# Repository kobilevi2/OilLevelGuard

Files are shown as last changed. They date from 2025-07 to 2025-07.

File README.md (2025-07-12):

# 🛢️ Oil Level Guard

## 🛢️ Overview

I have an oil tank that supplies heating to my house. After running out of oil more than once in the middle of winter — simply because I forgot to check the tank level — I decided to automate the process.

I developed a simple but effective project that automatically detects when the oil level in the tank drops below a certain threshold. To do this, I installed a liquid presence detector on the tank’s indicator pipe.

The sensor is connected to an ESP32-C6 microcontroller, which transmits the data via Zigbee to my Home Assistant setup.

## 📸 Project Images

Below are images of the final setup and installation:

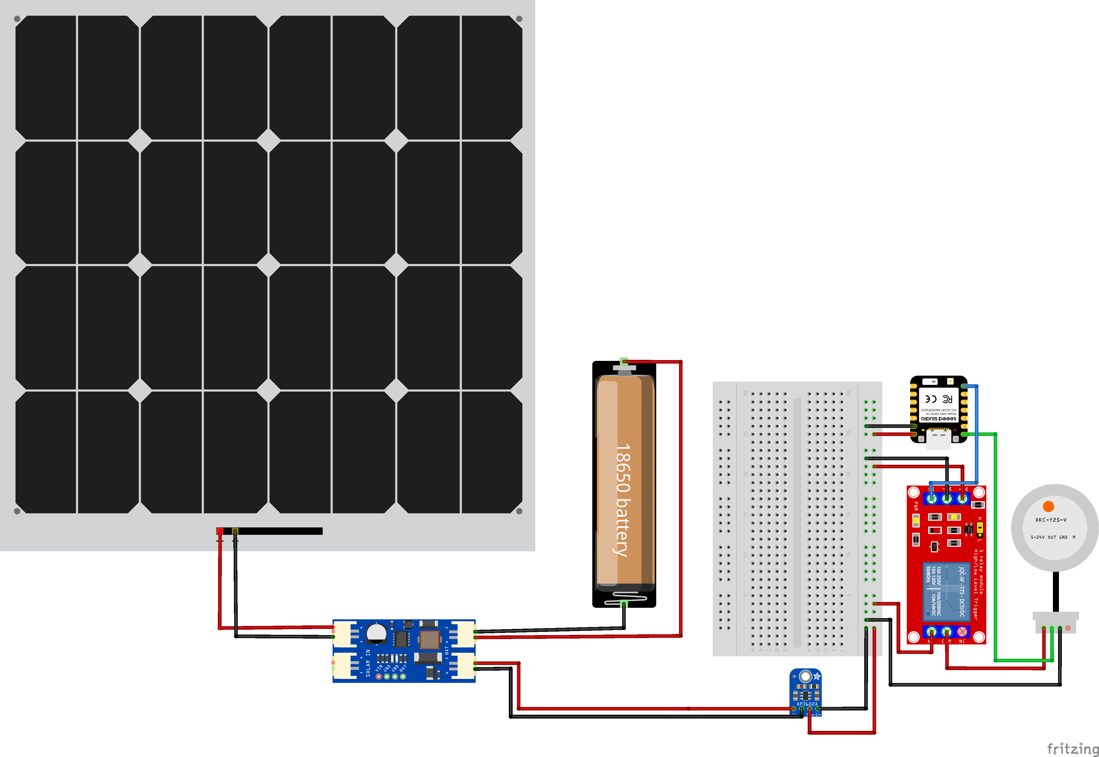
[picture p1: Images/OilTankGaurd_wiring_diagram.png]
Wiring Diagram
- 
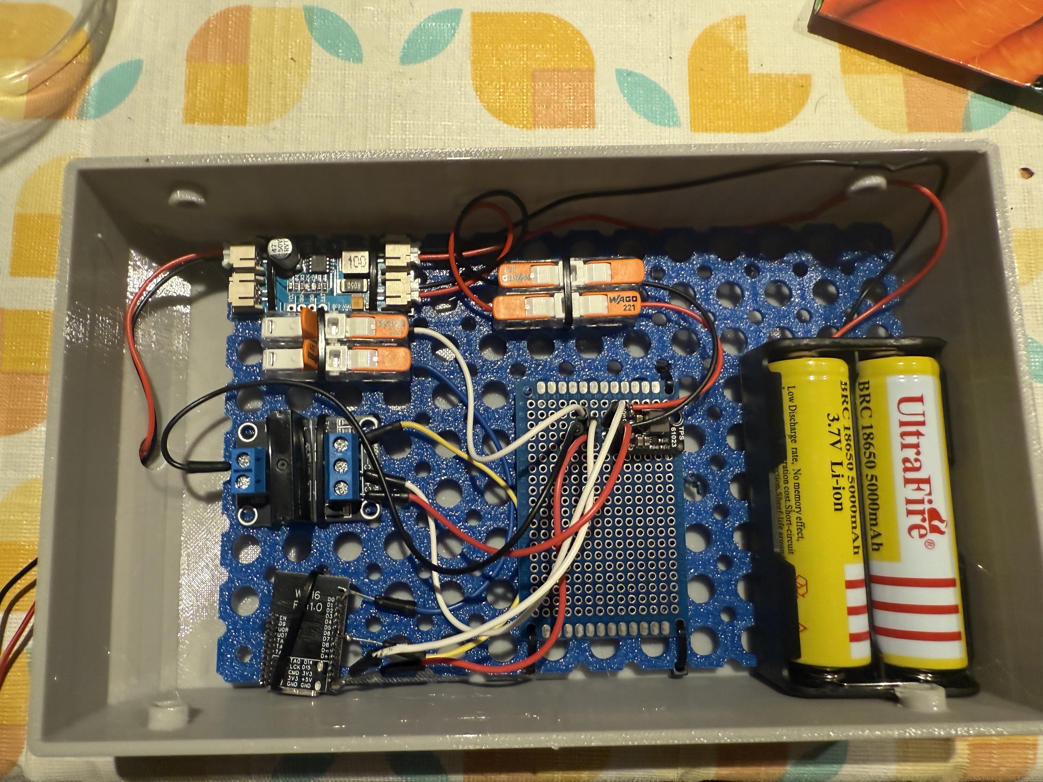
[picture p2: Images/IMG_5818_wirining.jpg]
Inside Wiring Layout
- 
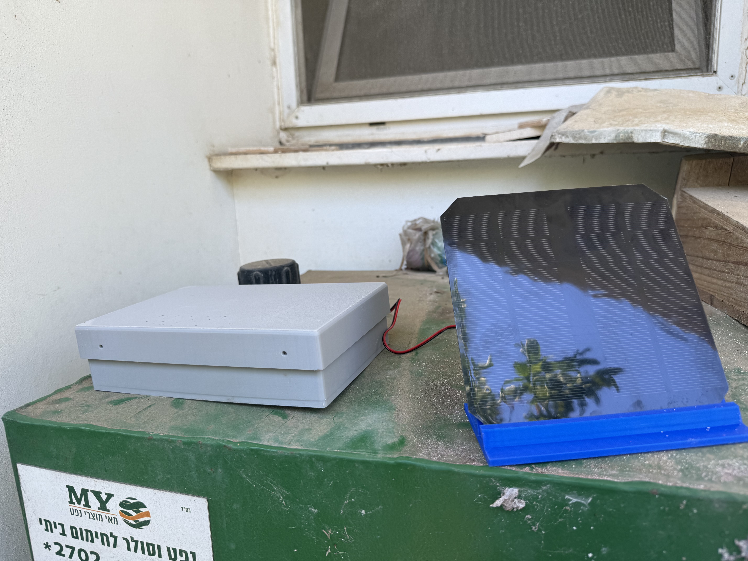
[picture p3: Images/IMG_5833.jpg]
Project Enclosure
- 
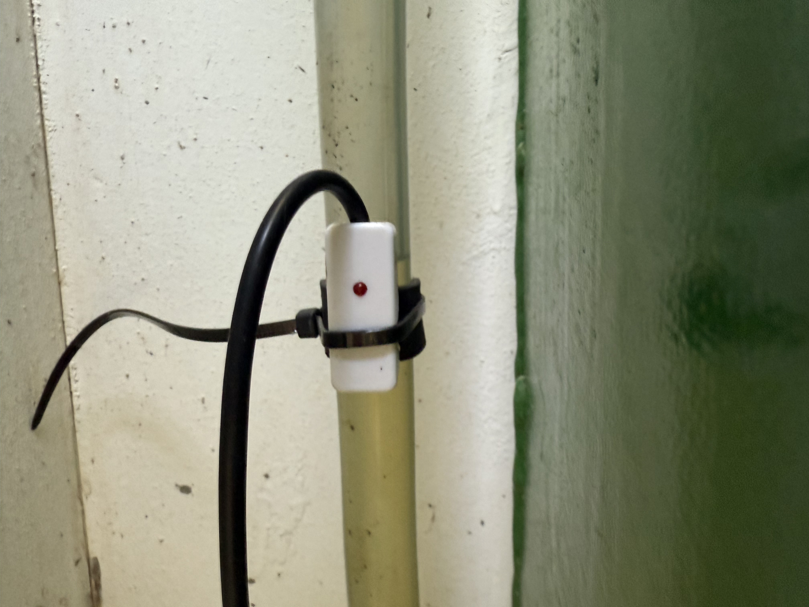
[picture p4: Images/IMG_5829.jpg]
Sensor Mounted on Oil Tank
- 

## 🔋 Power & Efficiency

The device is completely off-grid:

- Powered by a **6V solar panel** charging a **single 18650 battery**
- Uses a **relay** to power the sensor only during readings
- ESP32 wakes every **2 hours**, checks the level, transmits status, then enters **deep sleep**
- Optimized for ultra-low power usage

## 🛠️ How It Works

1. Every 2 hours, ESP32 wakes from deep sleep
2. It enables power to the sensor via relay
3. Sensor checks for oil presence
4. Status is transmitted via Zigbee to Home Assistant
5. ESP32 adds a slight random variation to readings (to overcome Zigbee's no-change-no-send bug)
6. Device goes back to sleep

## 📦 Bill of Materials

| #  | Component | Purpose | Model / Specs | Buy Link | Price (USD) |
|----|---|---|---|---|---|
| 1  | ESP32-C6 Dev Board | Controller (Zigbee + Wi-Fi 6) | ESP32-C6-WROOM-1 (USB-C) | [eBay](https://www.ebay.com/itm/286165884292) | ~$6.80 |
| 2  | Liquid Presence Sensor | Detect oil via pipe (non-contact) | XKC-Y26-PNP | Amazon / AliExpress | ~$10–15 |
| 3  | Solar Charger | MPPT battery charging from solar | CN3791 | AliExpress | ~$7.70 |
| 4  | Relay Module | Power control for sensor | Standard 1-channel 5V relay | AliExpress | ~$1–3 |
| 5  | 18650 Battery Holder | Battery housing | 1-cell 18650 holder | AliExpress | ~$1–2 |
| 6  | Solar Panel | Powers the system | 6V 1W (110×69 mm) | [AliExpress](https://www.aliexpress.com/item/1005002796119334.html) | ~$7.30 |
| 7  | Step-Up Converter | Boost 3.7V to 5V | MT3608 DC-DC Boost Module | [AliExpress](https://www.aliexpress.com/item/1005006678339221.html) | ~$3.64 |

## 🧰 Implementation Notes

- Sensor shows as a *temperature sensor* in Home Assistant:
  - Value > 90 = oil detected
  - Value < 10 = oil not detected
- Random offset added to avoid Zigbee not re-sending identical values
- Sensor is **non-invasive** for safety
- Adjust sensor sensitivity **after mounting**
- Use **zip ties** to secure the sensor to the pipe

## 🧱 3D Printed Enclosure

All components are mounted inside a custom 3D-printed enclosure:

- Box, Lid, and Solar Panel Stand available on [OnShape](https://cad.onshape.com/documents/b10629fecaf0ac9edbcd4630/w/6cedf870c4686d0133f1f7d6/e/6562cfb349b612dd35926ae9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)
- Use **PETG or ASA** filament (for outdoor durability)

In order to arrange all the components I’ve used the CheeseBoard (14×9), which you can find and print from here:
- STL Model: [https://makerworld.com/en/models/1489078-parametric-cheeseboard#profileId-1557285](https://makerworld.com/en/models/1489078-parametric-cheeseboard#profileId-1557285)
- More details about the CheeseBoard project: [https://makerworld.com/en/models/1475104-cheeseboard#profileId-1539374](https://makerworld.com/en/models/1475104-cheeseboard#profileId-1539374)

## 📁 Directory Structure

```
OilLevelGuard/
│
├── Docs/           # Documentation (Fritzing diagram, BOM)
├── Src/            # Source code for ESP32-C6
├── 3D/             # STEP files and STL models for enclosure
└── Images/         # Photos of installed system
```

## 🏠 Home Assistant Integration

The device integrates as a Zigbee temperature sensor. Use Home Assistant’s automation to interpret values and generate alerts when oil runs low.

## 📜 License

This project is open-source and available under the MIT License.

## 🤝 Contributing

Pull requests are welcome. For major changes, please open an issue first to discuss what you would like to change.

## 📬 Contact

For questions or suggestions, feel free to reach out via [my GitHub profile](https://github.com/koblevi2).

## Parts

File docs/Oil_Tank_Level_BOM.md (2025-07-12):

| Component | Purpose | Model / Specs | Buy Link | Price (USD) |
|:---|:---|:---|:---|:---|
| ESP32-C6 Development Board | Main controller with Zigbee + Wi-Fi 6 | ESP32-C6-WROOM-1 (USB-C) | https://www.ebay.com/itm/286165884292 | $6.80 |
| Liquid Presence Sensor | Detects oil level via indicator pipe  | XKC-Y26-PNP, non-contact | https://www.amazon.com/dp/B09QF8Y4P5 | $10–15 |
| Solar Charger Module | Charges battery from solar panel | CN3791 MPPT Solar Charger | https://www.aliexpress.com/item/1005002796119334.html | $7.70 |
| Relay Module (1-Channel, 5V) | Powers sensor only when needed | Standard 5V Relay | https://www.aliexpress.com/wholesale?SearchText=1+channel+5v+relay+module | $1–3 |
| 18650 Battery Holder | Holds the rechargeable battery | 1-cell 18650 holder | https://www.aliexpress.com/wholesale?SearchText=18650+battery+holder+1+slot | $1–2 |
| Solar Panel | Powers the system off-grid | 6V 1W Mini Panel (110×69 mm) | https://www.aliexpress.com/item/1005002796119334.html | $7.30 |
| Step-Up Converter | Boosts 3.7V (battery) to 5V | MT3608 DC-DC Boost Module | https://www.aliexpress.com/item/1005006678339221.html | $3.64 |

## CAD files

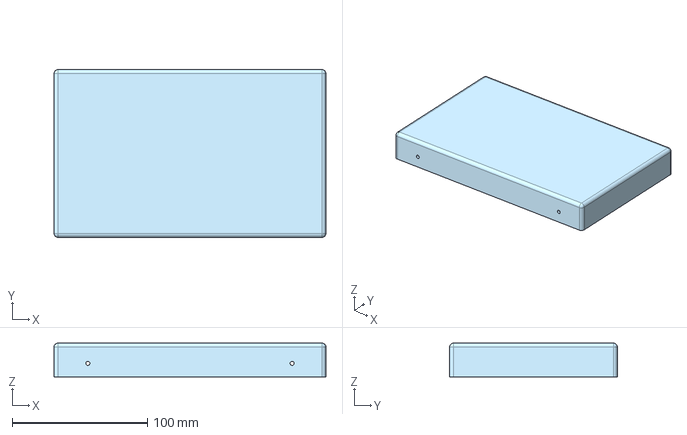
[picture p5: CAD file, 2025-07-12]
3D_Models/Box_part2.step
201.0 x 124.0 x 25.0 mm

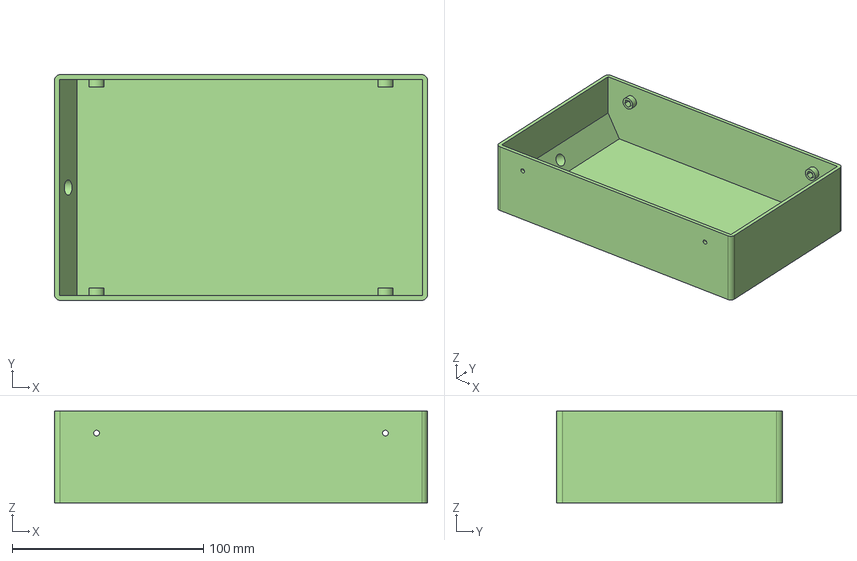
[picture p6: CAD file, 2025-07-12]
3D_Models/Box_part1.step
195.0 x 118.0 x 48.0 mm

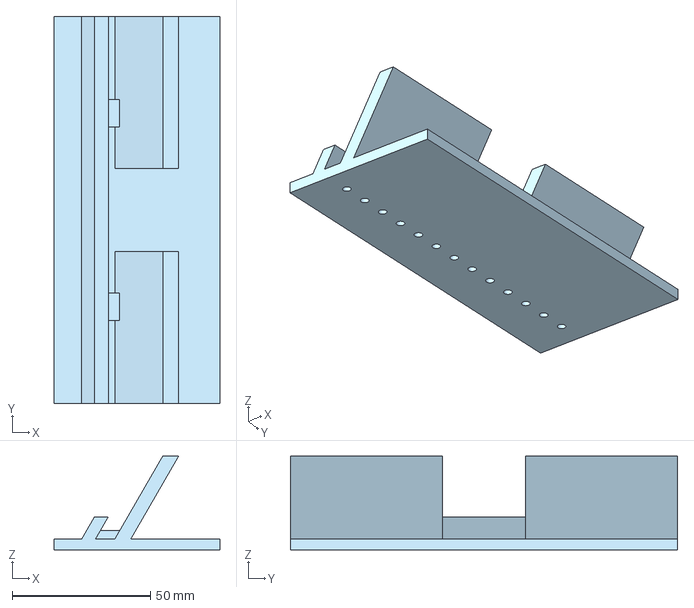
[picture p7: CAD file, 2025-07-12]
3D_Models/SolarPanelStand.step
60.0 x 140.0 x 34.0 mm

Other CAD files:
3D_Models/Box_part1.stl
3D_Models/Box_part2.stl
3D_Models/SolarPanelStand.stl

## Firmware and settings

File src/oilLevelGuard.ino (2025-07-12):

// Copyright 2024 Espressif Systems (Shanghai) PTE LTD
//
// Licensed under the Apache License, Version 2.0 (the "License");
// you may not use this file except in compliance with the License.
// You may obtain a copy of the License at
//
//     http://www.apache.org/licenses/LICENSE-2.0
//
// Unless required by applicable law or agreed to in writing, software
// distributed under the License is distributed on an "AS IS" BASIS,
// WITHOUT WARRANTIES OR CONDITIONS OF ANY KIND, either express or implied.
// See the License for the specific language governing permissions and
// limitations under the License.

/**
 * @brief This example demonstrates Zigbee temperature and humidity sensor Sleepy device.
 *
 * The example demonstrates how to use Zigbee library to create an end device temperature and humidity sensor.
 * The sensor is a Zigbee end device, which is reporting data to the Zigbee network.
 *
 * Proper Zigbee mode must be selected in Tools->Zigbee mode
 * and also the correct partition scheme must be selected in Tools->Partition Scheme.
 *
 * Please check the README.md for instructions and more detailed description.
 *
 * Created by Jan Procházka (https://github.com/P-R-O-C-H-Y/)
 */


#ifndef ZIGBEE_MODE_ED
#
error "Zigbee end device mode is not selected in Tools->Zigbee mode"
#endif

#include "Zigbee.h"

/* Zigbee temperature + humidity sensor configuration */
#define TEMP_SENSOR_ENDPOINT_NUMBER 10

#define uS_TO_S_FACTOR 1000000ULL /* Conversion factor for micro seconds to seconds */
#define TIME_TO_SLEEP  7190     // Sleep for 2 hours - 10 seconds     

uint8_t button = BOOT_PIN;

#define Liquid_Detection_Pin 0   //Input pin on sensor
#define RELAY_PIN 6              //Relay pin 

ZigbeeTempSensor zbTempSensor = ZigbeeTempSensor(TEMP_SENSOR_ENDPOINT_NUMBER);


/************************ Temp sensor *****************************/
void meausureAndSleep() {
  
  // Open the relay
  digitalWrite(RELAY_PIN, HIGH);
  Serial.println("Relay opened");


  // wait for few seconds
  delay (5000);
  
  // Measure temperature sensor value
  float temperature = 0; //temperatureRead();
  if (digitalRead(Liquid_Detection_Pin)) {
    Serial.println("Liquid Detected!");
    temperature = 90.0;
  }
  else {
    Serial.println("No Liquid!");
    temperature = 0.0;
  }
  
  // Close the relay
  digitalWrite(RELAY_PIN, LOW);


  // add random to the temp in order to asure that the device will report
  srand(time(0));
  float tmp = 10.0*(float)rand()/(float)(RAND_MAX);
  temperature +=tmp;

  // Use temperature value as humidity value to demonstrate both temperature and humidity
  float humidity = temperature;

  // Update temperature and humidity values in Temperature sensor EP
  zbTempSensor.setTemperature(temperature);
  zbTempSensor.setHumidity(humidity);

  // Report temperature and humidity values
  zbTempSensor.report();
  Serial.printf("Reported temperature: %.2f°C, Humidity: %.2f%%\r\n", temperature, humidity);

  // Add small delay to allow the data to be sent before going to sleep
  delay(5000);

  // Put device to deep sleep
  Serial.println("Going to sleep now");
  esp_deep_sleep_start();
}

/********************* Arduino functions **************************/

void setup() {
  Serial.begin(115200);  
  Serial.println("Starting ...");
  
  //Zigbee.factoryReset();

  // Init button switch
  pinMode(button, INPUT_PULLUP);

  pinMode(Liquid_Detection_Pin, INPUT);

  // Set the relay pin as output
  pinMode(RELAY_PIN, OUTPUT);

  // Configure the wake up source and set to wake up every 5 seconds
  esp_sleep_enable_timer_wakeup(TIME_TO_SLEEP * uS_TO_S_FACTOR);

  // Optional: set Zigbee device name and model
  zbTempSensor.setManufacturerAndModel("HomeMade", "LiquidDetector");

  // Set minimum and maximum temperature measurement value (10-50°C is default range for chip temperature measurement)
  zbTempSensor.setMinMaxValue(0, 100);

  // Set tolerance for temperature measurement in °C (lowest possible value is 0.01°C)
  zbTempSensor.setTolerance(1);

  // Set power source to battery and set battery percentage to measured value (now 100% for demonstration)
  // The value can be also updated by calling zbTempSensor.setBatteryPercentage(percentage) anytime
  zbTempSensor.setPowerSource(ZB_POWER_SOURCE_BATTERY, 100);

  // Add humidity cluster to the temperature sensor device with min, max and tolerance values
  zbTempSensor.addHumiditySensor(0, 100, 1);

  // Add endpoint to Zigbee Core
  Zigbee.addEndpoint(&zbTempSensor);

  // Create a custom Zigbee configuration for End Device with keep alive 10s to avoid interference with reporting data
  esp_zb_cfg_t zigbeeConfig = ZIGBEE_DEFAULT_ED_CONFIG();
  zigbeeConfig.nwk_cfg.zed_cfg.keep_alive = 10000;

  // When all EPs are registered, start Zigbee in End Device mode
  if (!Zigbee.begin(&zigbeeConfig, false)) {
    Serial.println("Zigbee failed to start!");
    Serial.println("Rebooting...");
    ESP.restart();
  }
  Serial.println("Connecting to network");
  while (!Zigbee.connected()) {
    Serial.print(".");
    delay(100);
  }
  Serial.println();
  Serial.println("Successfully connected to Zigbee network");

  // Delay approx 1s (may be adjusted) to allow establishing proper connection with coordinator, needed for sleepy devices
  delay(1000);
}


void loop() {
  // Checking button for factory reset
  if (digitalRead(button) == LOW) {  // Push button pressed
    // Key debounce handling
    delay(100);
    int startTime = millis();
    while (digitalRead(button) == LOW) {
      delay(50);
      if ((millis() - startTime) > 3000) {
        // If key pressed for more than 3secs, factory reset Zigbee and reboot
        Serial.println("Resetting Zigbee to factory and rebooting in 1s.");
        delay(1000);
        Zigbee.factoryReset();
      }
    }
  }

  // Call the function to measure temperature and put the device to sleep
  meausureAndSleep();
}
